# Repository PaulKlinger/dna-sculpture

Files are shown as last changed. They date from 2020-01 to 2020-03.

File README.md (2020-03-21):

# DNA Sculpture

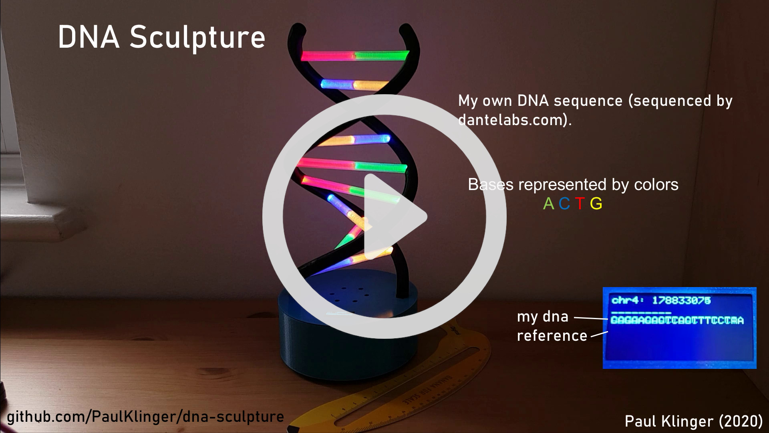
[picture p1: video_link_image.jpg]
(https://youtu.be/C1H_zHTX7Ds "Project video")


There are some in-progress photos of the build [here](https://imgur.com/a/wToFaz0).

## DNA
I had my DNA sequenced by [dantelabs.com](https://www.dantelabs.com/) (the 30X whole genome sequencing). They provide fastq, aligned bam, and vcf files, but just to understand some more about the process I redid the alignment with [bwa](https://github.com/lh3/bwa) and the variant calling with [bcftools](https://github.com/samtools/bcftools). (There are some issues with the called variants, see comments in dna.py, but that doesn't really matter for this project.) I've released all my genome files as [creative commons](https://creativecommons.org/publicdomain/zero/1.0/): [VCF](https://almoturg.com/paul_klinger_vcf_grch38.zip), [BAM](https://api.sequencing.com/download.ashx?id=27a5d439-af53-4887-940c-dd9895c1915e) (34 GiB!), [BAI](https://api.sequencing.com/download.ashx?id=ad2bf9d3-d068-4d9a-8b01-ec432784baf2).

## 3D Printed Parts
The 3D printed parts were printed on my [Prusa MK3S](https://shop.prusa3d.com/en/3d-printers/180-original-prusa-i3-mk3-kit.html) 3d printer.

The helices need quite a lot of support material, so the surface finish wasn't great. I removed the worst of it with some 300 grit sandpaper and then used a heat gun to smooth the surface.

The two parts of the case are held together with three m2 screws that screw into heat-set metal inserts in the top plate. The PCBs are retained with m2 screws into metal inserts in the bottom plate. The helices are friction fit into the top part of the case and secured with an m2 screw that screws into the plastic.

The base pairs between the two helices are printed in transparent PLA and the holes are filled with short pieces of 4mm PMMA side-glow fiberoptic. I glued a bit of aluminium foil to the end of the fiberoptic (where the two pieces meet in the middle) so the colors of the complementary bases don't mix. The base pairs are just friction fit into the helices, and the LEDs are sort-of retained by the little tabs at the end of the bases, although most of them broke off during assembly.

## Electronics & Software
The electronics are very simple, just a raspberry pi zero w, 18 WS2812B RGB LEDS in two strings of nine, a momentary button (for turning it on/off) and a diode (necessary for the button due to overlapping pin functions, see below).
The LEDS are connected with some 30 AWG wire, soldered directly to them. I assembled the LEDs already inside the two helices, adding one and then pulling the cables through to the next hole. That's absolutely horrible work, I'm pretty amazed it works at all. When putting the connecting transparent parts in they put pressure on the LEDs and it's quite likely that some of the connection fail and you have to fix it in place... 
Theoretically the WS2812B require an external capacitor (except for the new v5 version) but that would make assembly even more horrible. Thankfully it works fine without them.
The second PCB just contains a micro usb connector and a big capacitor, I used the [same PCB as for my satellite tracker](https://github.com/PaulKlinger/satellite_tracker/tree/master/PCBs/auxiliary).

The default I2C baudrate of the raspberry pi zero w is quite low, which limits the display to ~2 fps. Adding
```
dtparam=i2c_arm=on
dtparam=i2c1=on
dtparam=i2c1_baudrate=800000
```
to boot.config fixes this.

### On/off button
Getting both a single button for startup/shutdown and I2C (for the display) to work is a bit harder than it should be. When the RPi is shut down ("halt" state) it can only be woken up by connecting pin 3 (BCM numbering) to ground (or disconnecting and reconnecting power). But pin 3 is also the clock pin for the standard I2C port (i2c-1). Theoretically there's a second I2C, i2c-0 on pins 0/1 but I didn't manage to increase the baudrate for that. (Theoretically this should be possible using "dtparam=i2c_vc=on" to enable it and "dtparam=i2c_vc_baudrate=800000" to set the baudrate, but for me it stayed at the default (low) speed.)

The solution I found is by [Christian U. on stackexchange](https://raspberrypi.stackexchange.com/a/85316) (thanks!). He suggests connecting a diode from pin 3 to another GPIO (pin 4 in my case) and the button between pin 4 and ground. That way when the Pi is off it can be turned on by pushing the button (as current can flow from pin 3 to pin 4) but when the I2C peripheral pulls the clock line low this doesn't affect pin 4. When the button is pressed pin 4 is pulled low which triggers the shutdown (I'm using the gpiozero library for button handling). Pushing the button also pulls pin 3 low, so this messes up the I2C interface, but as the device is shutting down anyway this doesn't matter.

To make sure that the Pi wakes up when the button is pressed the forward voltage of the diode must be small enough. I tried a red LED but that didn't work, so I'm using an SS24 power diode now (the only other kind of diode I had at hand).

## Code
The code here is not very nice, and it's pretty slow, mostly because of the display library. But it's just fast enough for ~10 updates per second, which is about the limit of what is nice to look at anyway.

The file dna.service is the systemd service configuration used to start main.py on startup (mostly as a syntax reminder to myself).

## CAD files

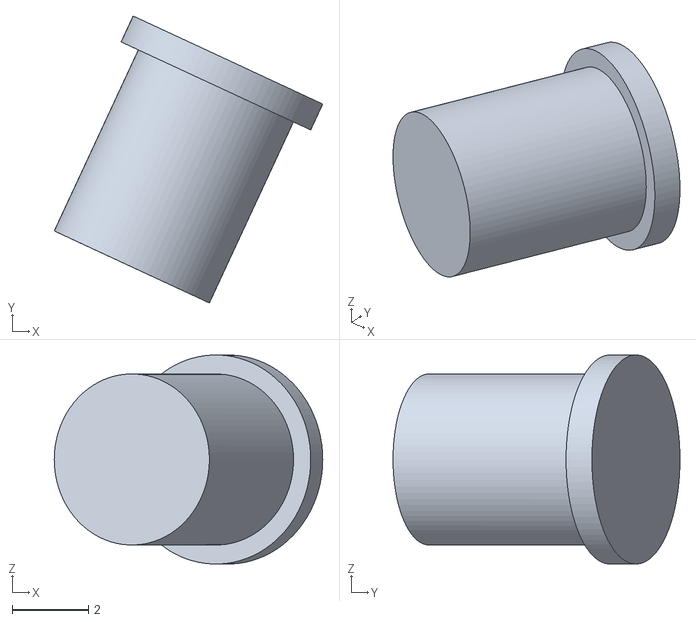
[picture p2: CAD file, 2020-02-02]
3d_models/button.stl
7.06 x 7.55 x 5.50

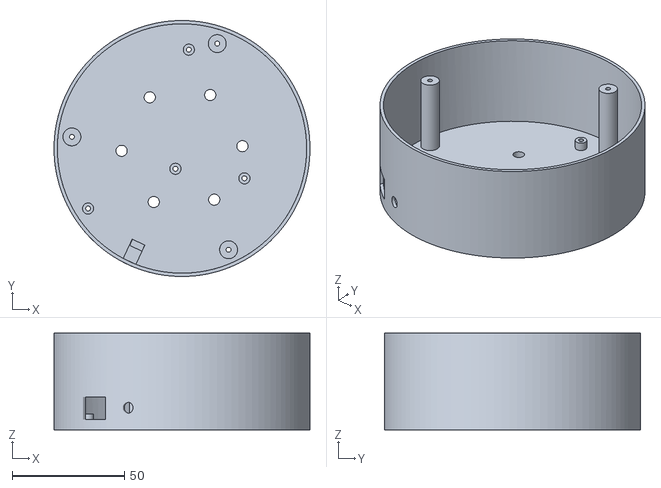
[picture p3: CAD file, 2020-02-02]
3d_models/case_bottom.stl
114.0 x 114.0 x 43.0

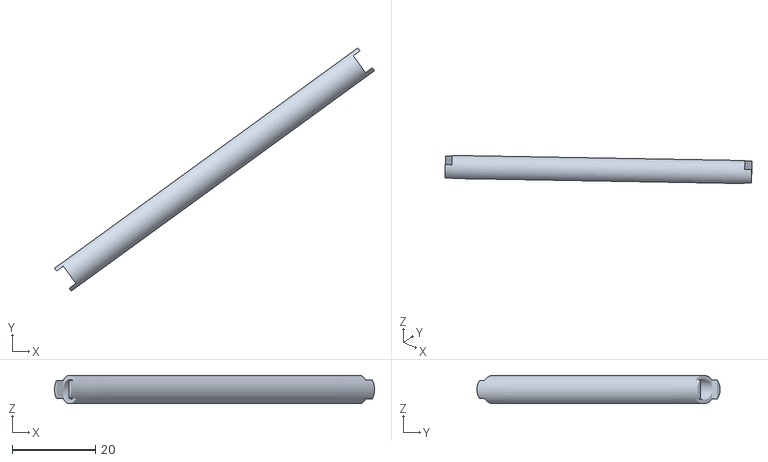
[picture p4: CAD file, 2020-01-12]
3d_models/base.stl
76.8 x 58.4 x 6.80

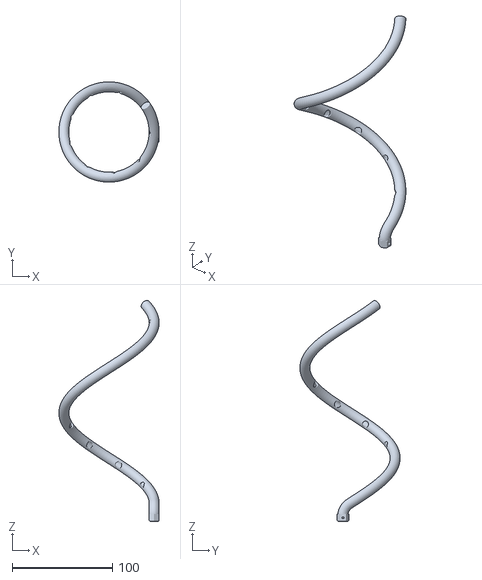
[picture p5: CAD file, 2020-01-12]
3d_models/helix.stl
100.0 x 100.0 x 220.4

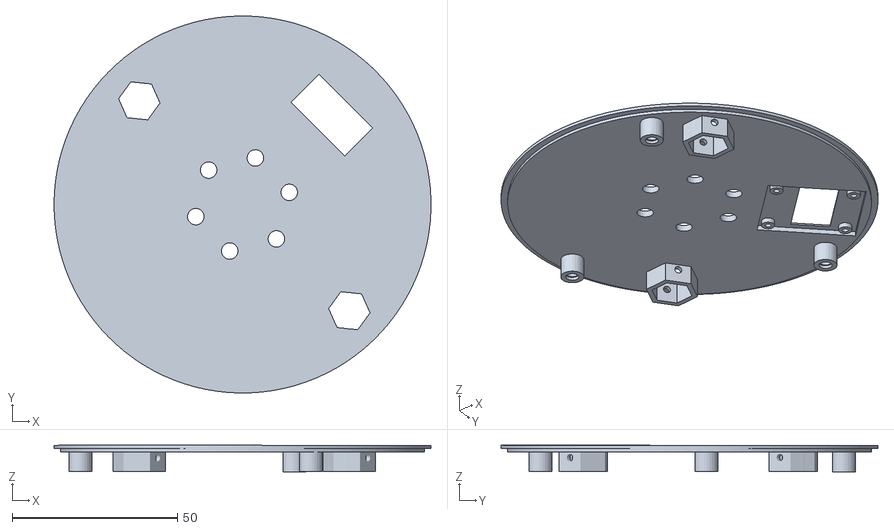
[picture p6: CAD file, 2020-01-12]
3d_models/case_top.stl
114.0 x 114.0 x 8.02

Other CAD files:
3d_models/dna.f3d

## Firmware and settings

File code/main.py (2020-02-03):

import board
from rpi_ws281x import ws, Color, PixelStrip
import busio
import adafruit_ssd1306
import gpiozero

from time import sleep, perf_counter
from typing import Iterator, Any, Tuple, List, Dict
from itertools import islice
import random
import logging
from subprocess import check_call
import queue

from dna import get_consensus_sequence, Locus, Base, RefStatus, read_fai, INVERSE_BASES
from config import (VCF_PATHS, CONTIGS, FASTA_PATH, FAI_PATH,
                    N_LEDS, LED_PIN_1, LED_PIN_2, HOMREF_BRIGHTNESS_FACTOR,
                    BASES_PER_SECOND, BASES_PER_SECOND_DIFF, JUMP_PROB, N_BASES_DISPLAYED)
from minimal_disp_replacements import MinimalMemoryFont


BASE_COLORS = {
    Base.T: (255, 0, 0),
    Base.C: (0, 0, 255),
    Base.A: (5, 152, 5),
    Base.G: (209, 103, 6)
}

FALLBACK_COLOR = (30, 30, 30)


class Screen(object):
    def __init__(self):
        i2c = busio.I2C(board.SCL, board.SDA, frequency=800000)
        self.display: adafruit_ssd1306.SSD1306_I2C = adafruit_ssd1306.SSD1306_I2C(
            128, 64, i2c)
        self.display.rotation = 2

        # replace the font class with a less complicated faster one
        self.display._font = MinimalMemoryFont()

    def update_screen(self, loci: List[Locus]) -> None:
        self.display.fill(0)
        self.display.text("{}: {}".format(
            loci[0].contig, loci[0].pos), 0, 0, 1)
        self.display.text("_" * N_LEDS, 0, 10, 1)
        self.display.text("".join(str(l.bases[1]) for l in loci), 0, 20, 1)
        self.display.text("".join(" " if l.ref_base == l.bases[1]
                                  else str(l.ref_base) for l in loci), 0, 30, 1)
        self._show()

    def show_message(self, message: str) -> None:
        self.display.fill(0)
        self.display.text(message, 10, 15, 1)
        self._show()

    def _show(self) -> None:
        # When the button is pressed this also pulls down the I2C clock line
        # as this is the only pin that can wake the Pi up from halt.
        # This shouldn't matter, as when the button is pressed we shut down anyway.
        try:
            self.display.show()
        except OSError:
            logging.warning("Display comm error. Button pressed?")


class DNAIterator(object):
    def __init__(self, ref_path: str, contigs: List[str], vcf_paths: Dict[str, str], fai_path: str):
        self.fai_index = read_fai(fai_path, vcf_paths.keys())
        self.contigs = contigs
        self.ref_path = ref_path
        self.vcf_paths = vcf_paths

    def iterate_loci(self, contig: str, start_pos: int) -> Iterator[Locus]:
        with open(self.ref_path, mode="r", encoding="utf-8") as ref_file:
            logging.info(
                "starting iteration from {}:{}".format(contig, start_pos))
            consensus_it = get_consensus_sequence(
                self.vcf_paths[contig], ref_file, self.fai_index[contig], start_pos)
            yield from consensus_it

    def iterate_from_random(self, redraw_invalid_start: bool = True) -> Iterator[Locus]:
        contig = random.choice(self.contigs)
        while True:
            start_pos = random.randint(0, self.fai_index[contig].len)
            l_it = self.iterate_loci(contig, start_pos)
            first_base = next(l_it)
            if not first_base.bases[1] in (Base.A, Base.G, Base.T, Base.C):
                continue
            yield first_base
            yield from l_it


def locus_to_colors(l: Locus) -> Tuple[Color, Color]:
    b = l.bases[1]
    c1 = BASE_COLORS.get(b, FALLBACK_COLOR)
    c2 = BASE_COLORS.get(INVERSE_BASES.get(b, None), FALLBACK_COLOR)

    if l.ref_status == RefStatus.hom_ref:
        c1 = tuple(int(x * HOMREF_BRIGHTNESS_FACTOR) for x in c1)
        c2 = tuple(int(x * HOMREF_BRIGHTNESS_FACTOR) for x in c2)
    return (Color(*c1), Color(*c2))


def iterate_sliding(source_it: Iterator[Any], n: int) -> Iterator[List[Any]]:
    """
    Iterates through source_it returning a sliding window of n outputs
    """
    res = list(islice(source_it, n))
    yield res
    for e in source_it:
        res = res[1:] + [e]
        yield res


class DNASculpture(object):
    def __init__(self):
        self.init_leds()
        self.display = Screen()
        self.button = gpiozero.Button(4, bounce_time=0.05)
        self.button.when_released = self.shutdown
        self.running = False

    def init_leds(self) -> None:
        self.strand1 = PixelStrip(N_LEDS, LED_PIN_1)
        self.strand2 = PixelStrip(N_LEDS, LED_PIN_2, channel=1)

        self.strand1.begin()
        self.strand2.begin()

    def shutdown(self) -> None:
        self.running = False
        logging.info("Shutting down")
        sleep(1)
        check_call(['sudo', 'poweroff'])
        sleep(10)

    def run(self) -> None:
        self.display.show_message("Loading DNA data...")
        dna_iterator = DNAIterator(FASTA_PATH, CONTIGS, VCF_PATHS, FAI_PATH)

        self.running = True
        while True:
            random_iter = dna_iterator.iterate_from_random(redraw_invalid_start=True)
            t0 = perf_counter()
            for seq in iterate_sliding(random_iter, N_BASES_DISPLAYED):
                if not self.running:
                    # This can't be in shutdown because the rpi_ws281x library is
                    # not threadsafe (causes segmentation fault).
                    for i in range(N_LEDS):
                        self.strand1.setPixelColor(i, Color(0, 0, 0))
                        self.strand2.setPixelColor(i, Color(0, 0, 0))
                    self.strand1.show()
                    self.strand2.show()
                    
                    while True:
                        # I2C is broken while the button is pressed
                        # hopefully it's released before we shut down...
                        self.display.show_message("")

                self.display.update_screen(seq)
                for i, l in enumerate(seq[:N_LEDS]):
                    c1, c2 = locus_to_colors(l)
                    self.strand1.setPixelColor(i, c1)
                    self.strand2.setPixelColor(i, c2)
                self.strand1.show()
                self.strand2.show()

                t1 = perf_counter()
                tdiff = t1 - t0
                if all(l.ref_status == RefStatus.hom_ref for l in seq[:N_LEDS]):
                    if tdiff > 1 / BASES_PER_SECOND:
                        logging.warning(f"Took {tdiff}s / base!")
                    sleep(max(1 / BASES_PER_SECOND - tdiff, 0))
                else:
                    sleep(max(1 / BASES_PER_SECOND_DIFF - tdiff, 0))
                t0 = perf_counter()
                if random.random() < JUMP_PROB:
                    logging.info("Jumping to new location")
                    self.display.show_message("Jumping to new location...")
                    break


if __name__ == "__main__":
    logging.basicConfig(level="DEBUG")
    dna = DNASculpture()
    dna.run()

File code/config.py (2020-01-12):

FASTA_PATH = "./data/GCA_000001405.15_GRCh38_no_alt_plus_hs38d1_analysis_set.fna"
FAI_PATH = "./data/GCA_000001405.15_GRCh38_no_alt_plus_hs38d1_analysis_set.fna.fai"

VCF_PATH_PATTERN = "./data/grch38_calls_filtered_{contig}.vcf"

CONTIGS = ["chr{}".format(i) for i in range(1,23)] + ["chrX", "chrY", "chrM"]

VCF_PATHS = {c: VCF_PATH_PATTERN.format(contig=c) for c in CONTIGS}

N_LEDS = 9
LED_PIN_1 = 18
LED_PIN_2 = 13
HOMREF_BRIGHTNESS_FACTOR = 0.25


N_BASES_DISPLAYED = 20
JUMP_PROB = 1 / 10000 # probability of jumping to a new location after each base
BASES_PER_SECOND = 10
BASES_PER_SECOND_DIFF = 2

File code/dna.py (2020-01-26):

import gzip
from collections import namedtuple
from enum import Enum
from typing import (Dict, List, Tuple, TextIO, BinaryIO,
                    Iterator, NamedTuple, Union, Iterable)
import logging
from itertools import zip_longest
from io import SEEK_END, SEEK_SET


class EnumNameOnly(Enum):
    def __repr__(self) -> str:
        return self.name

    def __str__(self) -> str:
        return self.name


class Base(EnumNameOnly):
    N = 0  # any
    A = 1
    C = 2
    T = 3
    G = 4
    X = 5  # missing
    R = 6  # G/A
    Y = 7  # T/C
    K = 8  # G/T
    M = 9  # A/C
    S = 10  # G/C
    W = 11  # A/T
    B = 12  # G/T/C
    D = 13  # G/A/T
    H = 14  # A/C/T
    V = 15  # G/C/A


B = Base

base_to_enum = {"N": Base.N, "A": Base.A,
                "C": Base.C, "T": Base.T, "G": Base.G,
                "R": Base.R, "Y": Base.Y, "K": Base.K,
                "M": Base.M, "S": Base.S, "W": Base.W,
                "B": Base.B, "D": Base.D, "H": Base.H,
                "V": Base.V}

INVERSE_BASES = {B.A: B.T, B.T: B.A, B.C: B.G, B.G: B.C}


class Genotype(EnumNameOnly):
    g00 = 0
    g01 = 1
    g11 = 2
    gxx = 3


class RefStatus(EnumNameOnly):
    hom_ref = 0
    het_mix = 1
    hom_alt = 2
    het_alt = 3


RS = RefStatus

gt_to_ref_status = {
    (0, 0): RS.hom_ref, (0, 1): RS.het_mix, (1, 1): RS.hom_alt,
    (1, 2): RS.het_alt, (2, 2): RS.hom_alt,
    (0,): RS.hom_ref, (1,): RS.hom_alt
}


class Locus(NamedTuple):
    """
    Genotype at one locus. Assumes diploid.

    bases: bases (same for homozygous, different for heterozygous)
    ref_status: relation to reference
    """
    contig: str
    pos: int
    bases: Tuple[Base, Base]
    ref_status: RefStatus
    ref_base: Base


class VariantType(EnumNameOnly):
    SNP = 0
    INS = 1
    DEL = 2
    OTHER = 3  # mostly mix between INS/DEL


VT = VariantType


class Variant(NamedTuple):
    """
    A variant (i.e. one line in a VCF file)

    contig: name of contig in reference
    pos: position in chromosome
    type: SNP/INS/DEL,...
    ref: reference base(s)
    alt: alternative bases
    qual: quality score
    filter: 'PASS' if valid
    info: info column
    gt: inferred genotype (0, 0) homozygous ref, (0, 1) heterozygous, (1, 1) homozygous alt
    pl: phred scaled probability of each genotype in order above (lower is more likely)
    """
    contig: str
    pos: int
    type: VariantType
    ref: List[Base]
    alts: List[List[Base]]
    qual: float
    filter: str
    info: str
    gt: Tuple[int, int]
    pl: str


FaiLine = namedtuple("FaiLine",
                     ["contig", "len", "start", "bapl", "bypl"])
FaiLine.__doc__ = """
An entry in a Fai file

contig: name of contig (i.e. chromosome)
len: # of bases in contig
start: byte index of contig start in fasta file
bapl: # of bases per line
bypl: # of bytes per line
"""


def read_fai(filename: str, contigs: Iterable[str]) -> Dict[str, FaiLine]:
    fai_index = {}

    with open(filename, encoding="utf-8") as f:
        for line in f:
            cols = line.strip().split("\t")
            if cols[0] in contigs:
                fai_index[cols[0]] = FaiLine(cols[0],
                                             *[int(x) for x in cols[1:]])
    return fai_index


class VCFFile(object):
    def __init__(self, filename: str, contig: str, filter_status: bool = True):
        self.filename = filename
        self.contig = contig
        self.filter_status = filter_status

    def iterate_from_pos(self, pos: int) -> Iterator[Variant]:
        with open(self.filename, "rb") as f:
            self._search_for_pos(f, pos)
            yield from self._iterate_vcf(f)

    def _search_for_pos(self, file: BinaryIO, pos: int) -> None:
        """
        Binary search through the VCF file to find the position of
        the next variant call after pos
        """
        logging.info(
            f"Starting binary search for next variant after {self.contig}:{pos} in {self.filename}")

        file_length = file.seek(0, SEEK_END)
        file.seek(0)

        lower = 0
        upper = file_length
        new_pos = None

        while lower < upper:
            file.seek(lower + (upper - lower) // 2)
            file.readline()  # skip to next complete line
            new_pos = file.tell()
            if new_pos == upper:
                break

            line = file.readline().decode("ascii")
            if line is None:
                # we reached the end of the file
                upper = new_pos
                continue

            v = self._parse_vcf_line(line)
            # assuming that invalid lines only occur at the beginning
            # hopefully that's true...
            if v is None or v.pos < pos:
                lower = new_pos
            else:
                upper = new_pos

            logging.debug(f"{self.contig}:{lower}-{upper}")

        file.seek(upper)
        logging.info(
            f"Found next variant.")

    def _parse_vcf_line(self, line: str) -> Union[Variant, None]:
        if not line.startswith(self.contig):
            return None
        cols = line.strip().split("\t")
        ref = [base_to_enum[c] for c in cols[3]]
        alts = [[base_to_enum[c] for c in cs] for cs in cols[4].split(",")]

        if len(ref) == 1 and all(len(a) == 1 for a in alts):
            v_type = VT.SNP
        elif len(ref) == 1 and all(len(a) > 1 for a in alts):
            v_type = VT.INS
        elif len(ref) > 1 and all(len(a) == 1 for a in alts):
            v_type = VT.DEL
        else:
            v_type = VT.OTHER

        gt, pl = cols[-1].split(":")
        gt = tuple(int(gi) for gi in gt.split("/"))
        v = Variant(contig=cols[0], pos=int(cols[1]), type=v_type,
                    ref=ref, alts=alts, qual=float(cols[5]),
                    filter=cols[6], info=cols[7], gt=gt, pl=pl)
        return v

    def _iterate_vcf(self, file: BinaryIO) -> Iterator[Variant]:
        while True:
            line = file.readline()
            if not line:
                break
            v = self._parse_vcf_line(line.decode("ascii"))
            if v is None or (self.filter_status and v.filter != "PASS"):
                continue
            yield v


class InvalidVariantsError(ValueError):
    pass
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

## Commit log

2019-12-26 bugfix, forgot to change iterate_ref argument
    [dna.py]
2020-01-07 Working basic sequence display
    still missing random jumping and info screen
    [main.py]
2020-01-11 type fixes, added comment
    [dna.py, main.py]
2020-01-11 use separate process for updating the display
    This doesn't really make it any better, probably because the Pi zero W has only one core
    and the limiting factor seems to be the python code of the display library, not the io.
    [config.py, main.py]
2020-01-11 switched back to single process, makes display updates much more consistent
2020-01-12 added 3d models and Fusion 360 source for 3d printed parts
    [Base_Bottom.stl, Base_Top.stl, base.stl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]
2020-01-15 bugfix for X/Y/M SNPs
    [dna.py]
2020-01-19 bugfix: can't set attribute on namedtuple
    [dna.py]
2020-01-26 renamed stls
    [case_bottom.stl, case_top.stl]
2020-01-26 updated Fusion 360 source file
    [dna.f3d]
2020-01-26 added some more info about 3d prints to readme
2020-02-02 Added power button to CAD/models (not yet functional)
    [button.stl, case_bottom.stl, dna.f3d]
2020-02-03 added shutdown button, restructuring
2020-02-04 added info about on/off button issues/solution
